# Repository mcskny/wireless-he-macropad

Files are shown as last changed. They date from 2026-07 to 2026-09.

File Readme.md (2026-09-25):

# Custom Wireless Hall Effect (HE) & Digital Macropad




A high-performance, open-source **wireless mechanical macropad** that solves the battery drain issue of wireless Hall Effect keyboards. Featuring a **Hybrid Dual-Sensor Architecture (Analog HE + Digital Switches)**, MOSFET power gating, esports-grade algorithms (Rapid Trigger, SnapTap/SOCD), 4 hardware layers, and a high-efficiency **TPS6300x Buck-Boost power system**.

---

## Gallery & Preview

<!-- Project photos and renders -->
<table>
  <tr>
    <td align="center" width="50%">
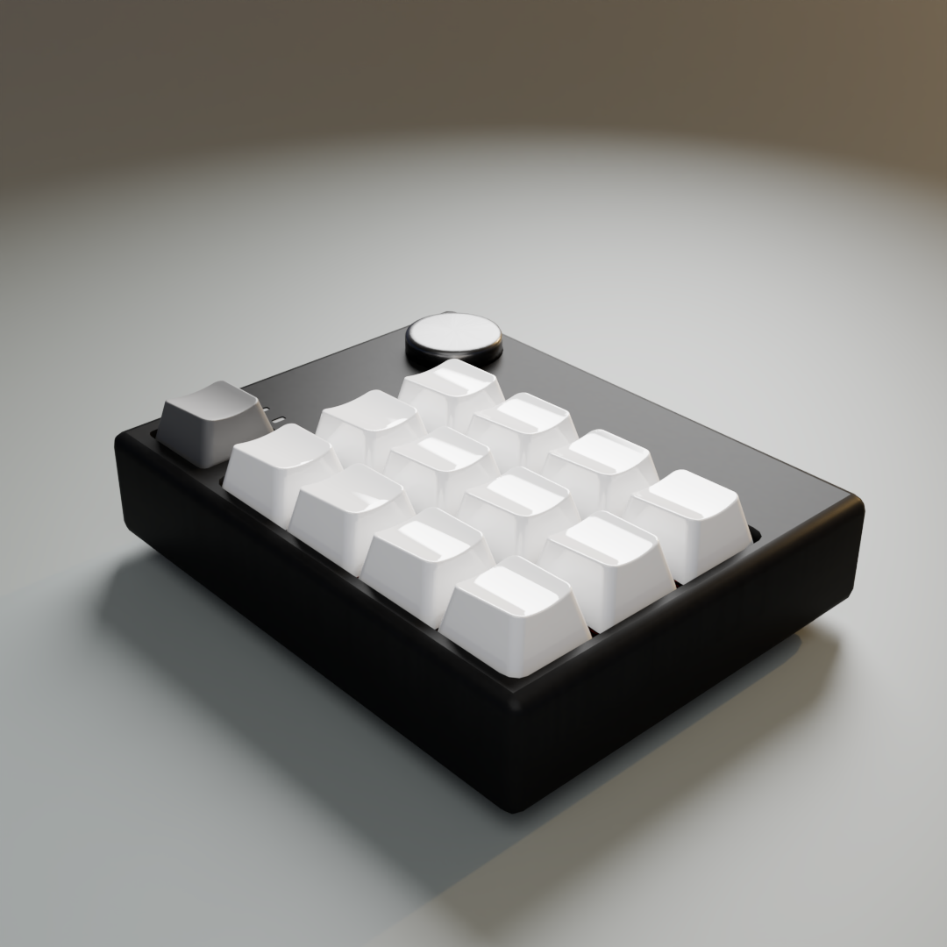
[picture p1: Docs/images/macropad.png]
3D Render
      
      <br>
      <b>3D Enclosure Render</b>
    </td>
    <td align="center" width="50%">
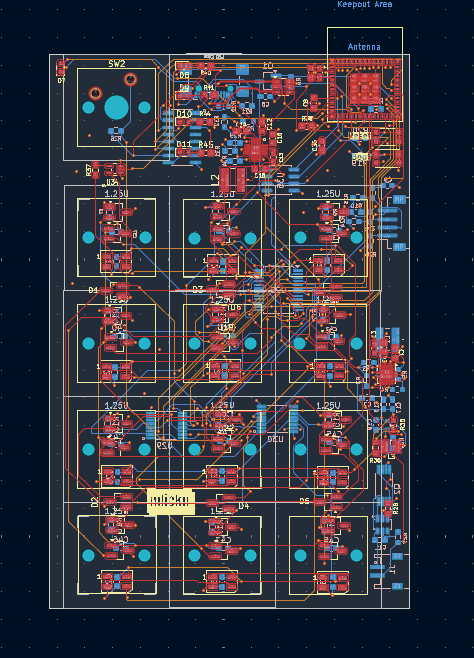
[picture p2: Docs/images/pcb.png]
PCB Design
      
      <br>
      <b>4-Layer PCB Design</b>
    </td>
  </tr>
</table>

---

## The Core Innovation

Wireless Hall Effect (HE) keyboards traditionally suffer from severe battery drain due to the constant current consumption of linear magnetic Hall ICs (~3-5mA per key). 

This project solves the battery crisis by implementing a **MOSFET-gated Hybrid Power System**:
- When idle, power to energy-hungry analog Hall sensors is completely cut via MOSFET switches.
- Keypresses are detected instantly via ultra-low-power digital switches, which trigger the MOSFET to power up the analog sensors on demand.

---

## Key Features

###  Smart Power System & Operation Modes
- **MOSFET Power Gating:** Hardware-level power cutoff for analog Hall Effect ICs.
- **3 Dynamic Power Modes:**
  -  **Digital Mode:** Operates exclusively on digital switches for ultra-low power consumption and maximum battery longevity.
  -  **Hybrid Mode (Smart Wake):** Digital switches remain active; pressing any key instantly powers on the Analog HE sensors via MOSFETs for a configurable duration.
  -  **Aggressive Mode:** Analog HE sensors remain continuously powered for zero-latency competitive esports performance.

---

## Repository & Component Architecture

This repository uses a **modular C architecture** built on top of the ESP-IDF framework:

```text
wireless-he-macropad/
├── Docs/                           # Documentation & Images
│   └── images/                     # Photos, PCB diagrams, 3D renders
├── Firmware/                       # ESP-IDF Firmware Codebase
│   ├── common/                     # Shared protocol definitions (keyboard_protocol.h)
│   ├── macropad-sender/            # Keyboard (Transmitter) Firmware
│   └── dongle-receiver/            # USB Dongle (Receiver) Firmware
|
├── Hardware/                       # KiCad PCB Files & Gerber Exports
│   ├── macropad.kicad_pro
│   ├── macropad.kicad_sch
│   ├── macropad.kicad_pcb
│   └── gerbers/                    # Production Gerber zip files
├── build_docker.bat                # Windows Docker build script
└── build_docker.sh                 # Linux/macOS Docker build script
```

---

## How to Build Firmware (Using Docker)

No local ESP-IDF toolchain installation is required. Firmware for both the **Transmitter** and **Receiver** can be built inside a clean, containerized Docker environment.

### Prerequisites
- [Docker Desktop](https://www.docker.com/products/docker-desktop/) installed and running.

### 1. Build Both Firmwares
Run the automated build script for your operating system:

**Windows (CMD / PowerShell):**
```cmd
build_docker.bat
```

**Linux / macOS:**
```bash
chmod +x build_docker.sh
./build_docker.sh
```

### 2. Clean Build Artifacts
To clear temporary CMake build caches:
```cmd
build_docker.bat clean
```

The compiled binary files (`.bin`) will be generated inside:
- **Transmitter:** `firmware/macropad-sender/build/`
- **Receiver:** `firmware/dongle-receiver/build/`

---

## How to Flash Firmware to Hardware

You can flash the generated binary files (`.bin`) to your ESP32 boards using either of the following methods:

### Method 1: Web-Based Flasher (Recommended - No Install Needed)
1. Open **[Espressif Web Serial Flasher](https://espressif.github.io/esptool-js/)** in Google Chrome or Microsoft Edge.
2. Connect your ESP32 board via USB and click **Connect**.
3. Select the generated binary files from your `build/` folder:
   - `0x1000` -> `bootloader.bin`
   - `0x8000` -> `partition-table.bin`
   - `0x10000` -> `macropad-sender.bin` (or `dongle-receiver.bin`)
4. Click **Program**.

### Method 2: Command Line (`esptool.py`)
If you have Python and `esptool` installed:
```bash
pip install esptool

# Flash Transmitter (Replace COM3 with your port)
esptool.py -p COM3 -b 921600 write_flash 0x10000 firmware/macropad-sender/build/macropad-sender.bin

# Flash Receiver
esptool.py -p COM4 -b 921600 write_flash 0x10000 firmware/dongle-receiver/build/dongle-receiver.bin
```

---

Distributed under the **MIT License**. See `LICENSE` for more information.

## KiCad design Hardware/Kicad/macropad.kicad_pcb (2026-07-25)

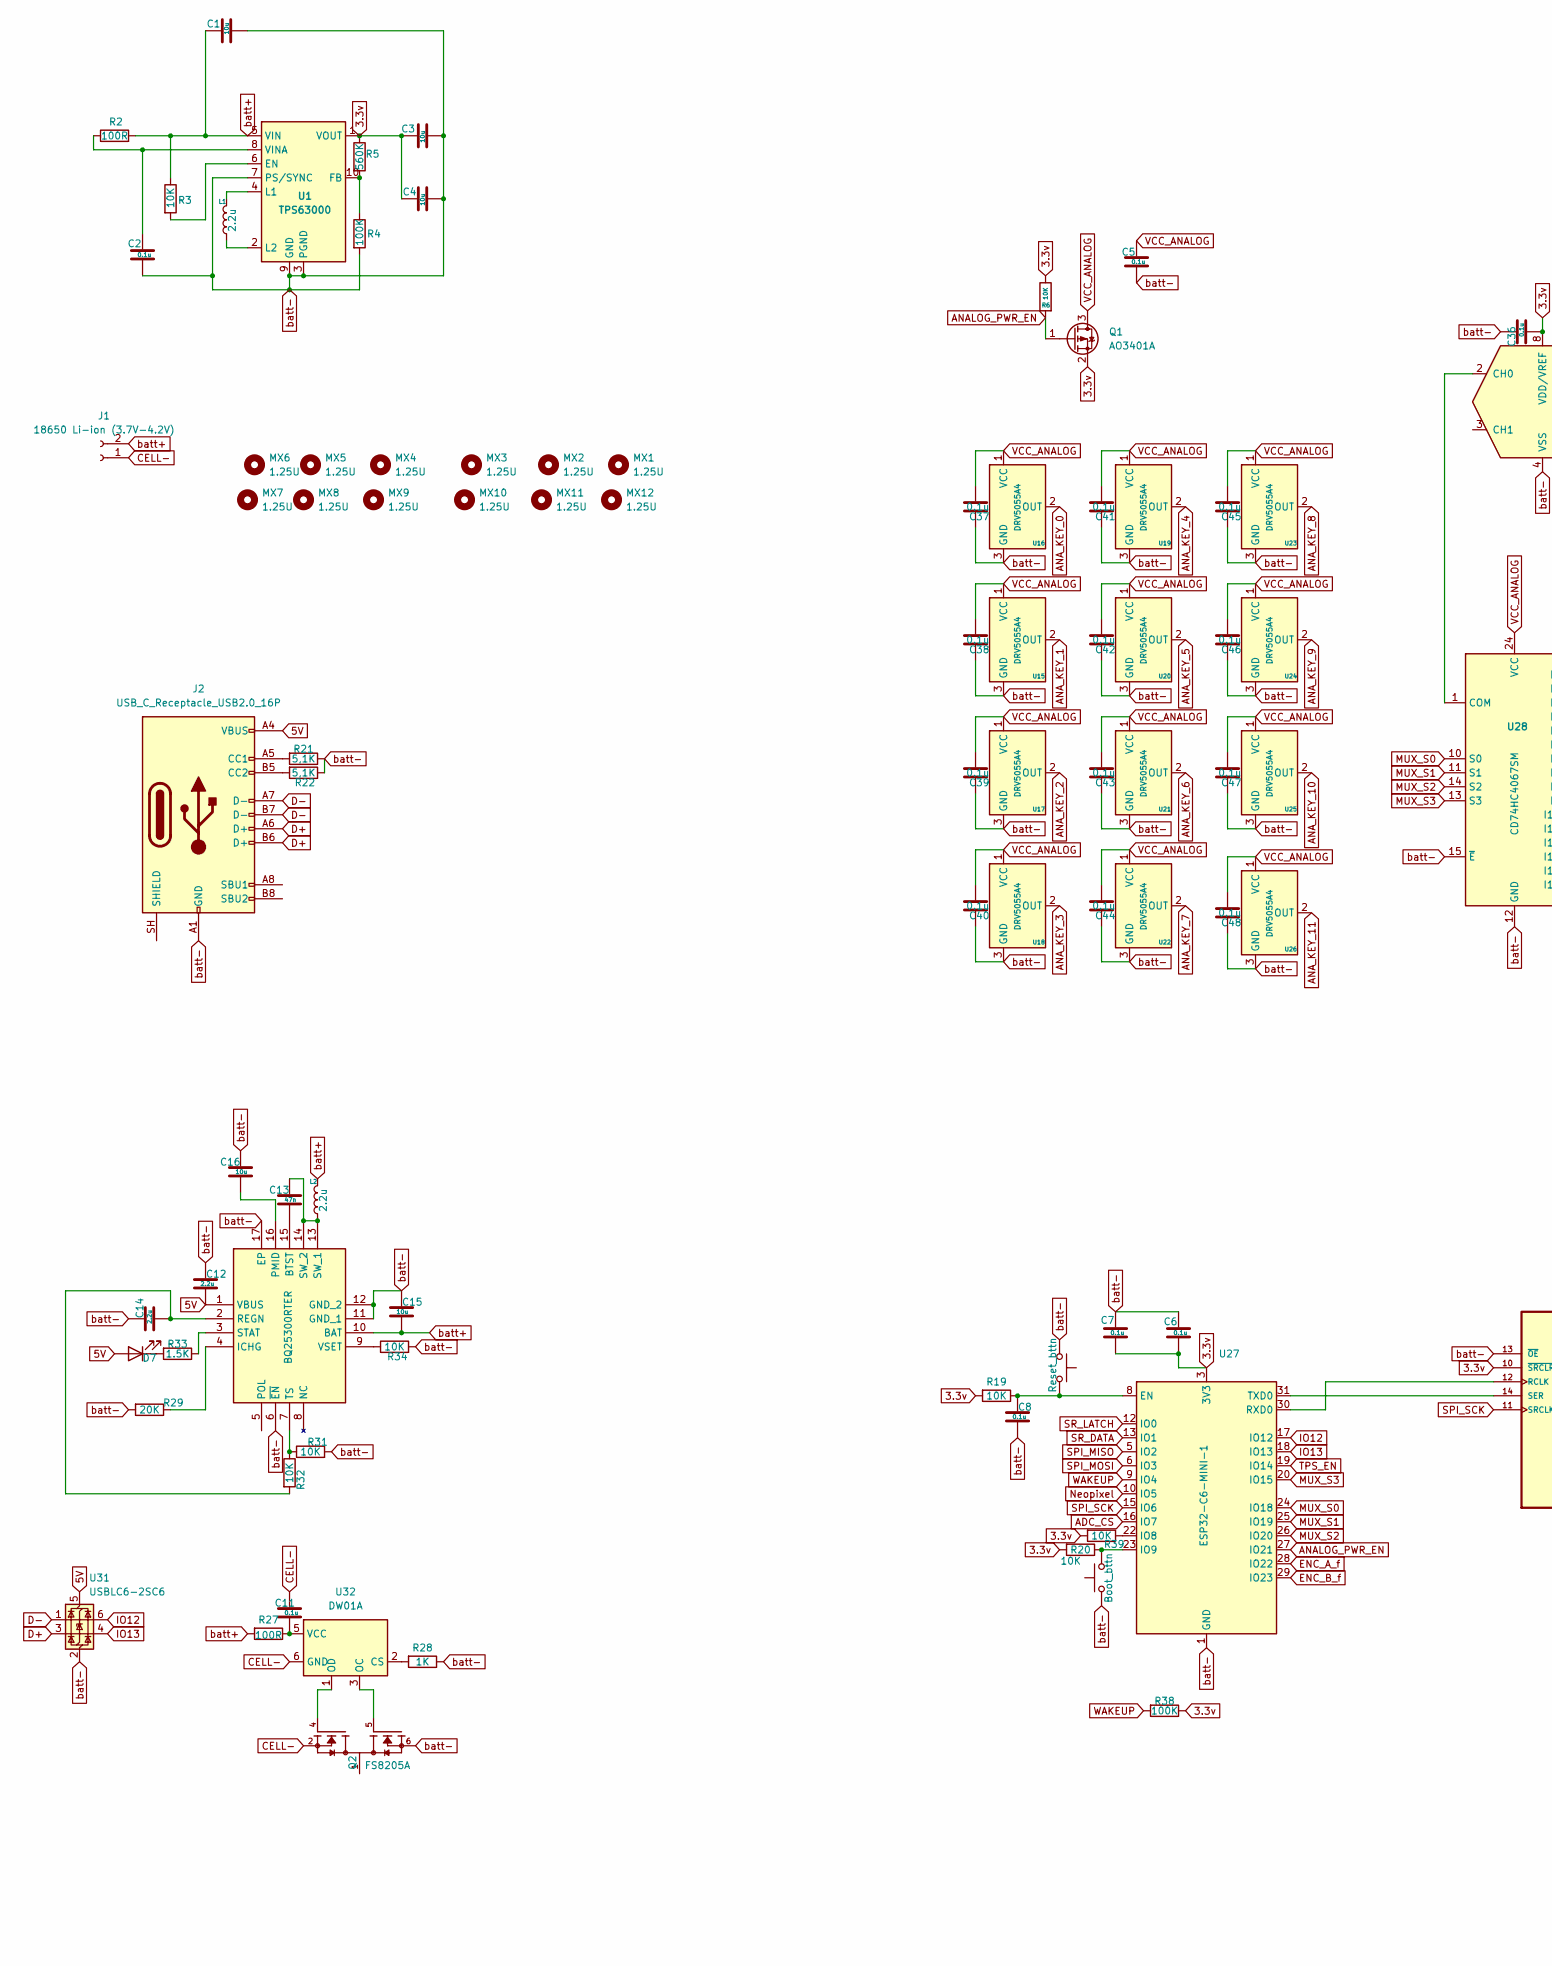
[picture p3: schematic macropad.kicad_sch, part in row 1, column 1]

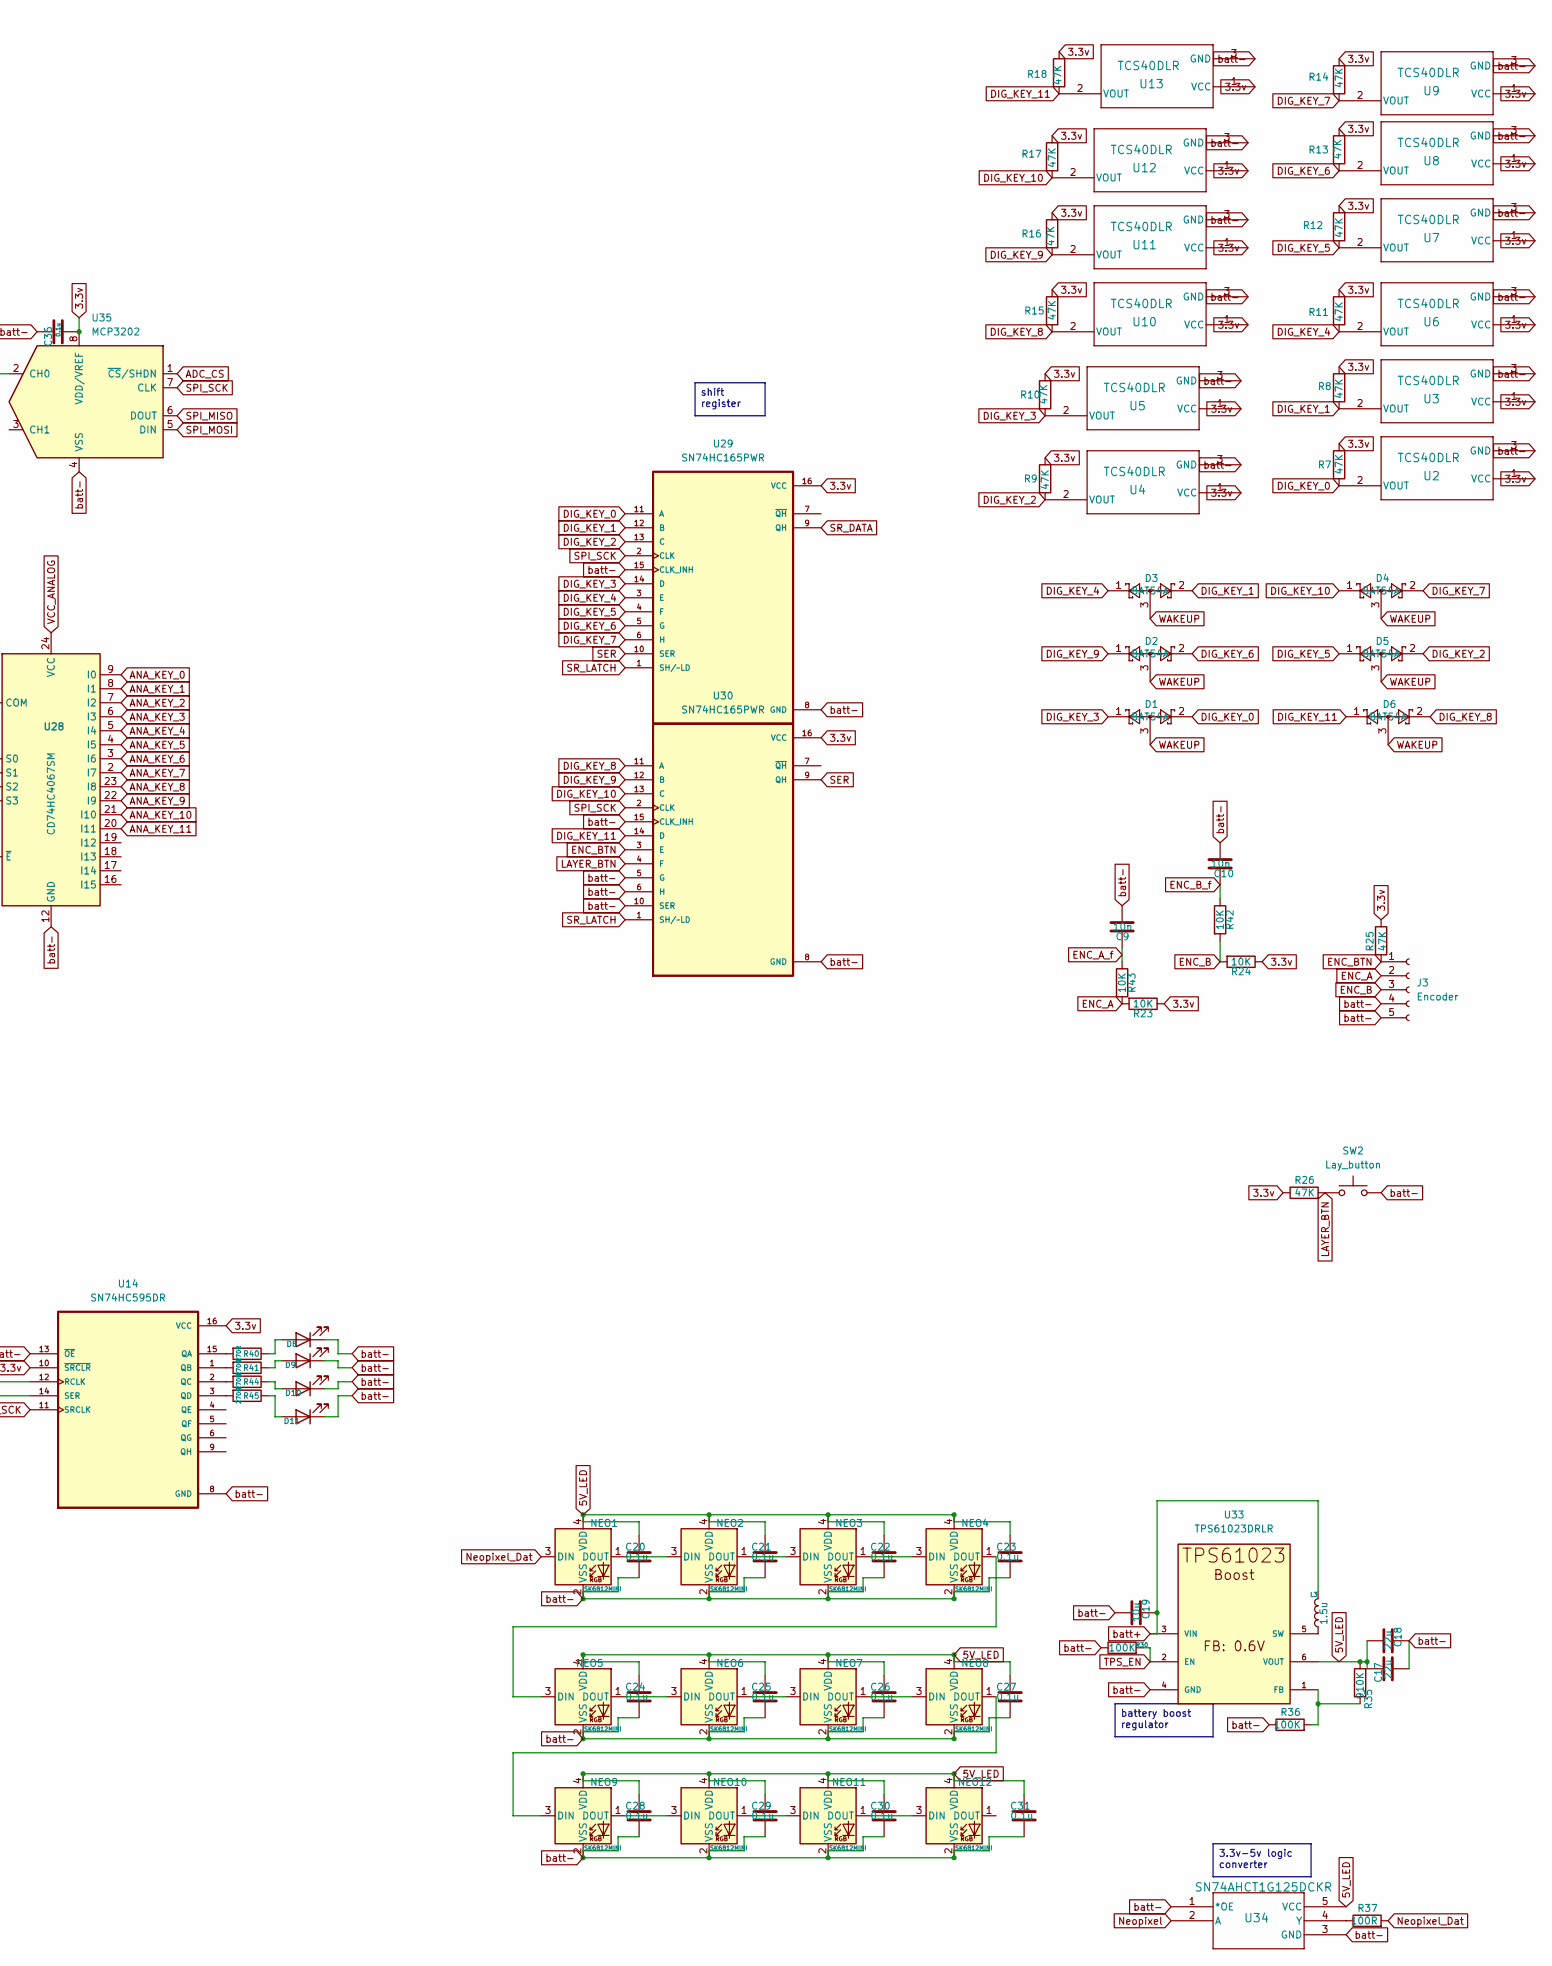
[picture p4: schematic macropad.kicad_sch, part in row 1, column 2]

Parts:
C1, C3, C4, C15, C16, C19: 10u; C_0603_1608Metric_Pad1.08x0.95mm_HandSolder
C2, C5, C6, C7, C8, C11, C20, C21, C22, C23, C24, C25, C26, C27, C28, C29, C30, C31, C36, C37, C38, C39, C40, C41, C42, C43, C44, C45, C46, C47, C48: 0.1u; C_0603_1608Metric_Pad1.08x0.95mm_HandSolder
C9, C10: 10n; C_0603_1608Metric_Pad1.08x0.95mm_HandSolder
C12, C14: 2.2u; C_0603_1608Metric_Pad1.08x0.95mm_HandSolder
C13: 47n; C_0603_1608Metric_Pad1.08x0.95mm_HandSolder
C17, C18: 22u; C_0603_1608Metric_Pad1.08x0.95mm_HandSolder
D1, D2, D3, D4, D5, D6: BAT54A; SOT-23_Handsoldering
D7, D8, D9, D10, D11: LED; LED_0603_1608Metric
J1: 18650 Li-ion (3.7V-4.2V); 648102131822
J2: USB_C_Receptacle_USB2.0_16P; USB_C_Receptacle_GCT_USB4110
J3: Encoder; SM04BPASS1TBTLFSN
L1, L2: 2.2u; SRN4030HA2R2Y
L3: 1.5u; INDC2520X100N
MX1, MX2, MX3, MX4, MX5, MX6, MX7, MX8, MX9, MX10, MX11, MX12: 1.25U; switchsocket
NEO1, NEO2, NEO3, NEO4, NEO5, NEO6, NEO7, NEO8, NEO9, NEO10, NEO11, NEO12: SK6812MINI; LED_SK6812MINI_PLCC4_3.5x3.5mm_P1.75mm
Q1: AO3401A; SOT-23_Handsoldering
Q2: FS8205A; SOP65P640X120-8N; PARTREV 1.7
R2, R27, R37: 100R; R_0603_1608Metric_Pad0.98x0.95mm_HandSolder
R3, R6, R19, R20, R23, R24, R31, R32, R34, R39, R42, R43: 10K; R_0603_1608Metric_Pad0.98x0.95mm_HandSolder
R4, R30, R36, R38: 100K; R_0603_1608Metric_Pad0.98x0.95mm_HandSolder
R5: 560K; R_0603_1608Metric_Pad0.98x0.95mm_HandSolder
R7, R8, R9, R10, R11, R12, R13, R14, R15, R16, R17, R18, R25, R26: 47K; R_0603_1608Metric_Pad0.98x0.95mm_HandSolder
R21, R22: 5,1K; R_0603_1608Metric_Pad0.98x0.95mm_HandSolder
R28: 1K; R_0603_1608Metric_Pad0.98x0.95mm_HandSolder
R29: 20K; R_0603_1608Metric_Pad0.98x0.95mm_HandSolder
R33: 1.5K; R_0603_1608Metric_Pad0.98x0.95mm_HandSolder
R35: 910K; R_0603_1608Metric_Pad0.98x0.95mm_HandSolder
R40, R41, R44, R45: 270R; R_0603_1608Metric_Pad0.98x0.95mm_HandSolder
SW1: Boot_bttn; SW_Push_1P1T_NO_CK_KMR2
SW2: Lay_button; SW_Cherry_MX_1.00u_PCB
SW3: Reset_bttn; SW_Push_1P1T_NO_CK_KMR2
U1: TPS63000; Texas_DRC0010J_ThermalVias
U2, U3, U4, U5, U6, U7, U8, U9, U10, U11, U12, U13: TCS40DLR; SOT-23_Handsoldering
U14: SN74HC595DR; SOIC127P600X175-16N
U15, U16, U17, U18, U19, U20, U21, U22, U23, U24, U25, U26: DRV5055A4; SOT-23_Handsoldering
U27: ESP32-C6-MINI-1
U28: CD74HC4067SM; SSOP-24_5.3x8.2mm_P0.65mm
U29, U30: SN74HC165PWR; SOP65P640X120-16N
U31: USBLC6-2SC6; SOT-23-6
U32: DW01A; SOT-23-6
U33: TPS61023DRLR; SOT563-ORI
U34: SN74AHCT1G125DCKR; DCK5
U35: MCP3202; SOIC-8_3.9x4.9mm_P1.27mm
Z1: BQ25300RTER; QFN50P300X300X80-17N-D; Mouser Part Number 595-BQ25300RTER

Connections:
3.3v: C3.1, C4.1, C6.2, C7.2, C36.2, Q1.2 (S), R5.1, R6.1, R7.2, R8.2, R9.2, R10.2, R11.2, R12.2, R13.2, R14.2, R15.2, R16.2, R17.2, R18.2, R19.2, R20.2, R23.1, R24.1, R25.1, R26.1, R38.1, R39.2, U1.1 (VOUT), U2.1 (VCC), U3.1 (VCC), U4.1 (VCC), U5.1 (VCC), U6.1 (VCC), U7.1 (VCC), U8.1 (VCC), U9.1 (VCC), U10.1 (VCC), U11.1 (VCC), U12.1 (VCC), U13.1 (VCC), U14.10 (~SRCLR), U14.16 (VCC), U27.3 (3V3), U29.16 (VCC), U30.16 (VCC), U35.8 (VDD/VREF)
5V: C12.1, D7.2 (A), J2.A4 (VBUS), J2.A9 (VBUS), J2.B4 (VBUS), J2.B9 (VBUS), U31.5 (VBUS), Z1.1 (VBUS)
5V_LED: C17.1, C18.2, C20.1, C21.1, C22.1, C23.1, C24.1, C25.1, C26.1, C27.1, C28.1, C29.1, C30.1, C31.1, NEO1.4 (VDD), NEO2.4 (VDD), NEO3.4 (VDD), NEO4.4 (VDD), NEO5.4 (VDD), NEO6.4 (VDD), NEO7.4 (VDD), NEO8.4 (VDD), NEO9.4 (VDD), NEO10.4 (VDD), NEO11.4 (VDD), NEO12.4 (VDD), R35.2, U33.6 (VOUT), U34.5 (VCC)
ADC_CS: U27.16 (IO7), U35.1 (~CS/SHDN)
ANALOG_PWR_EN: Q1.1 (G), R6.2, U27.27 (IO21)
ANA_KEY_0: U16.2 (OUT), U28.9 (I0)
ANA_KEY_1: U15.2 (OUT), U28.8 (I1)
ANA_KEY_2: U17.2 (OUT), U28.7 (I2)
ANA_KEY_3: U18.2 (OUT), U28.6 (I3)
ANA_KEY_4: U19.2 (OUT), U28.5 (I4)
ANA_KEY_5: U20.2 (OUT), U28.4 (I5)
ANA_KEY_6: U21.2 (OUT), U28.3 (I6)
ANA_KEY_7: U22.2 (OUT), U28.2 (I7)
ANA_KEY_8: U23.2 (OUT), U28.23 (I8)
ANA_KEY_9: U24.2 (OUT), U28.22 (I9)
ANA_KEY_10: U25.2 (OUT), U28.21 (I10)
ANA_KEY_11: U26.2 (OUT), U28.20 (I11)
CELL-: C11.1, J1.1, Q2.2, Q2.3, U32.6 (GND)
D+: J2.A6 (D+), J2.B6 (D+), U31.3 (I/O2)
D-: J2.A7 (D-), J2.B7 (D-), U31.1 (I/O1)
DIG_KEY_0: D1.2, R7.1, U2.2 (VOUT), U29.11 (A)
DIG_KEY_1: D3.2, R8.1, U3.2 (VOUT), U29.12 (B)
DIG_KEY_2: D5.2, R9.1, U4.2 (VOUT), U29.13 (C)
DIG_KEY_3: D1.1, R10.1, U5.2 (VOUT), U29.14 (D)
DIG_KEY_4: D3.1, R11.1, U6.2 (VOUT), U29.3 (E)
DIG_KEY_5: D5.1, R12.1, U7.2 (VOUT), U29.4 (F)
DIG_KEY_6: D2.2, R13.1, U8.2 (VOUT), U29.5 (G)
DIG_KEY_7: D4.2, R14.1, U9.2 (VOUT), U29.6 (H)
DIG_KEY_8: D6.2, R15.1, U10.2 (VOUT), U30.11 (A)
DIG_KEY_9: D2.1, R16.1, U11.2 (VOUT), U30.12 (B)
DIG_KEY_10: D4.1, R17.1, U12.2 (VOUT), U30.13 (C)
DIG_KEY_11: D6.1, R18.1, U13.2 (VOUT), U30.14 (D)
ENC_A: J3.2, R23.2, R43.2
ENC_A_f: C9.1, R43.1, U27.28 (IO22)
ENC_B: J3.3, R24.2, R42.2
ENC_BTN: J3.1, R25.2, U30.3 (E)
ENC_B_f: C10.1, R42.1, U27.29 (IO23)
IO12: U27.17 (IO12), U31.6 (I/O1)
IO13: U27.18 (IO13), U31.4 (I/O2)
LAYER_BTN: R26.2, SW2.1, U30.4 (F)
MUX_S0: U27.24 (IO18), U28.10 (S0)
MUX_S1: U27.25 (IO19), U28.11 (S1)
MUX_S2: U27.26 (IO20), U28.14 (S2)
MUX_S3: U27.20 (IO15), U28.13 (S3)
Neopixel: U27.10 (IO5), U34.2 (A)
Neopixel_Dat: NEO1.3 (DIN), R37.2
unnamed: D7.1 (K), R33.2
unnamed: D8.2 (A), R40.1
unnamed: D9.2 (A), R41.1
unnamed: D10.2 (A), R44.1
unnamed: D11.2 (A), R45.1
unnamed: J2.A5 (CC1), R21.2
unnamed: J2.B5 (CC2), R22.2
unnamed: NEO1.1 (DOUT), NEO2.3 (DIN)
unnamed: NEO2.1 (DOUT), NEO3.3 (DIN)
unnamed: NEO3.1 (DOUT), NEO4.3 (DIN)
unnamed: NEO4.1 (DOUT), NEO5.3 (DIN)
unnamed: NEO5.1 (DOUT), NEO6.3 (DIN)
unnamed: NEO6.1 (DOUT), NEO7.3 (DIN)
unnamed: NEO7.1 (DOUT), NEO8.3 (DIN)
unnamed: NEO8.1 (DOUT), NEO9.3 (DIN)
unnamed: NEO9.1 (DOUT), NEO10.3 (DIN)
unnamed: NEO10.1 (DOUT), NEO11.3 (DIN)
unnamed: NEO11.1 (DOUT), NEO12.3 (DIN)
unnamed: Q2.1, Q2.8
unnamed: R3.2, U1.6 (EN)
unnamed: R4.1, R5.2, U1.10 (FB)
unnamed: L1.2, U1.4 (L1)
unnamed: L1.1, U1.2 (L2)
unnamed: C2.1, R2.1, U1.8 (VINA)
unnamed: R40.2, U14.15 (QA)
unnamed: R41.2, U14.1 (QB)
unnamed: R44.2, U14.2 (QC)
unnamed: R45.2, U14.3 (QD)
unnamed: U14.7 (QH), U14.9 (QH)
unnamed: U14.12 (RCLK), U27.30 (RXD0)
unnamed: U14.14 (SER), U27.31 (TXD0)
unnamed: C8.2, R19.1, SW3.2, U27.8 (EN)
unnamed: R39.1, U27.22 (IO8)
unnamed: R20.1, SW1.2, U27.23 (IO9)
unnamed: U28.1 (COM), U35.2 (CH0)
unnamed: R28.2, U32.2 (CS)
unnamed: Q2.5, U32.3 (OC)
unnamed: Q2.4, U32.1 (OD)
unnamed: C11.2, R27.1, U32.5 (VCC)
unnamed: R35.1, R36.2, U33.1 (FB)
unnamed: L3.1, U33.5 (SW)
unnamed: R37.1, U34.4 (Y)
unnamed: C13.1, Z1.15 (BTST)
unnamed: R29.1, Z1.4 (ICHG)
unnamed: C16.1, Z1.16 (PMID)
unnamed: C14.1, R32.2, Z1.2 (REGN)
unnamed: R33.1, Z1.3 (STAT)
unnamed: C13.2, L2.1, Z1.13 (SW_1), Z1.14 (SW_2)
unnamed: R31.1, R32.1, Z1.7 (TS)
unnamed: R34.1, Z1.9 (VSET)
SER: U29.10 (SER), U30.9 (QH)
SPI_MISO: U27.5 (IO2), U35.6 (DOUT)
SPI_MOSI: U27.6 (IO3), U35.5 (DIN)
SPI_SCK: U14.11 (SRCLK), U27.15 (IO6), U29.2 (CLK), U30.2 (CLK), U35.7 (CLK)
SR_DATA: U27.13 (IO1), U29.9 (QH)
SR_LATCH: U27.12 (IO0), U29.1 (SH/~LD), U30.1 (SH/~LD)
TPS_EN: R30.2, U27.19 (IO14), U33.2 (EN)
VCC_ANALOG: C5.1, C37.2, C38.2, C39.2, C40.2, C41.2, C42.2, C43.2, C44.2, C45.2, C46.2, C47.2, C48.2, Q1.3 (D), U15.1 (VCC), U16.1 (VCC), U17.1 (VCC), U18.1 (VCC), U19.1 (VCC), U20.1 (VCC), U21.1 (VCC), U22.1 (VCC), U23.1 (VCC), U24.1 (VCC), U25.1 (VCC), U26.1 (VCC), U28.24 (VCC)
WAKEUP: D1.3, D2.3, D3.3, D4.3, D5.3, D6.3, R38.2, U27.9 (IO4)
batt+: C1.1, C15.1, C19.1, J1.2, L2.2, L3.2, R2.2, R3.1, R27.2, U1.5 (VIN), U33.3 (VIN), Z1.10 (BAT)
batt-: C1.2, C2.2, C3.2, C4.2, C5.2, C6.1, C7.1, C8.1, C9.2, C10.2, C12.2, C14.2, C15.2, C16.2, C17.2, C18.1, C19.2, C20.2, C21.2, C22.2, C23.2, C24.2, C25.2, C26.2, C27.2, C28.2, C29.2, C30.2, C31.2, C36.1, C37.1, C38.1, C39.1, C40.1, C41.1, C42.1, C43.1, C44.1, C45.1, C46.1, C47.1, C48.1, D8.1 (K), D9.1 (K), D10.1 (K), D11.1 (K), J2.A1 (GND), J2.A12 (GND), J2.B1 (GND), J2.B12 (GND), J3.4, J3.5, NEO1.2 (VSS), NEO2.2 (VSS), NEO3.2 (VSS), NEO4.2 (VSS), NEO5.2 (VSS), NEO6.2 (VSS), NEO7.2 (VSS), NEO8.2 (VSS), NEO9.2 (VSS), NEO10.2 (VSS), NEO11.2 (VSS), NEO12.2 (VSS), Q2.6, Q2.7, R4.2, R21.1, R22.1, R28.1, R29.2, R30.1, R31.2, R34.2, R36.1, SW1.1, SW2.2, SW3.1, U1.3 (PGND), U1.7 (PS/SYNC), U1.9 (GND), U1.11 (PGND), U2.3 (GND), U3.3 (GND), U4.3 (GND), U5.3 (GND), U6.3 (GND), U7.3 (GND), U8.3 (GND), U9.3 (GND), U10.3 (GND), U11.3 (GND), U12.3 (GND), U13.3 (GND), U14.8 (GND), U14.13 (~OE), U15.3 (GND), U16.3 (GND), U17.3 (GND), U18.3 (GND), U19.3 (GND), U20.3 (GND), U21.3 (GND), U22.3 (GND), U23.3 (GND), U24.3 (GND), U25.3 (GND), U26.3 (GND), U27.1 (GND), U27.2 (GND), U27.11 (GND), U27.14 (GND), U27.36 (GND), U27.37 (GND), U27.38 (GND), U27.39 (GND), U27.40 (GND), U27.41 (GND), U27.42 (GND), U27.43 (GND), U27.44 (GND), U27.45 (GND), U27.46 (GND), U27.47 (GND), U27.48 (GND), U27.49 (GND), U27.50 (GND), U27.51 (GND), U27.52 (GND), U27.53 (GND), U28.12 (GND), U28.15 (~E), U29.8 (GND), U29.15 (CLK_INH), U30.5 (G), U30.6 (H), U30.8 (GND), U30.10 (SER), U30.15 (CLK_INH), U31.2 (GND), U33.4 (GND), U34.1 (*OE), U34.3 (GND), U35.4 (VSS), Z1.6 (~EN), Z1.11 (GND_1), Z1.12 (GND_2), Z1.17 (EP)

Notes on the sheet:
3.3v-5v logic converter
battery boost regulator
shift register

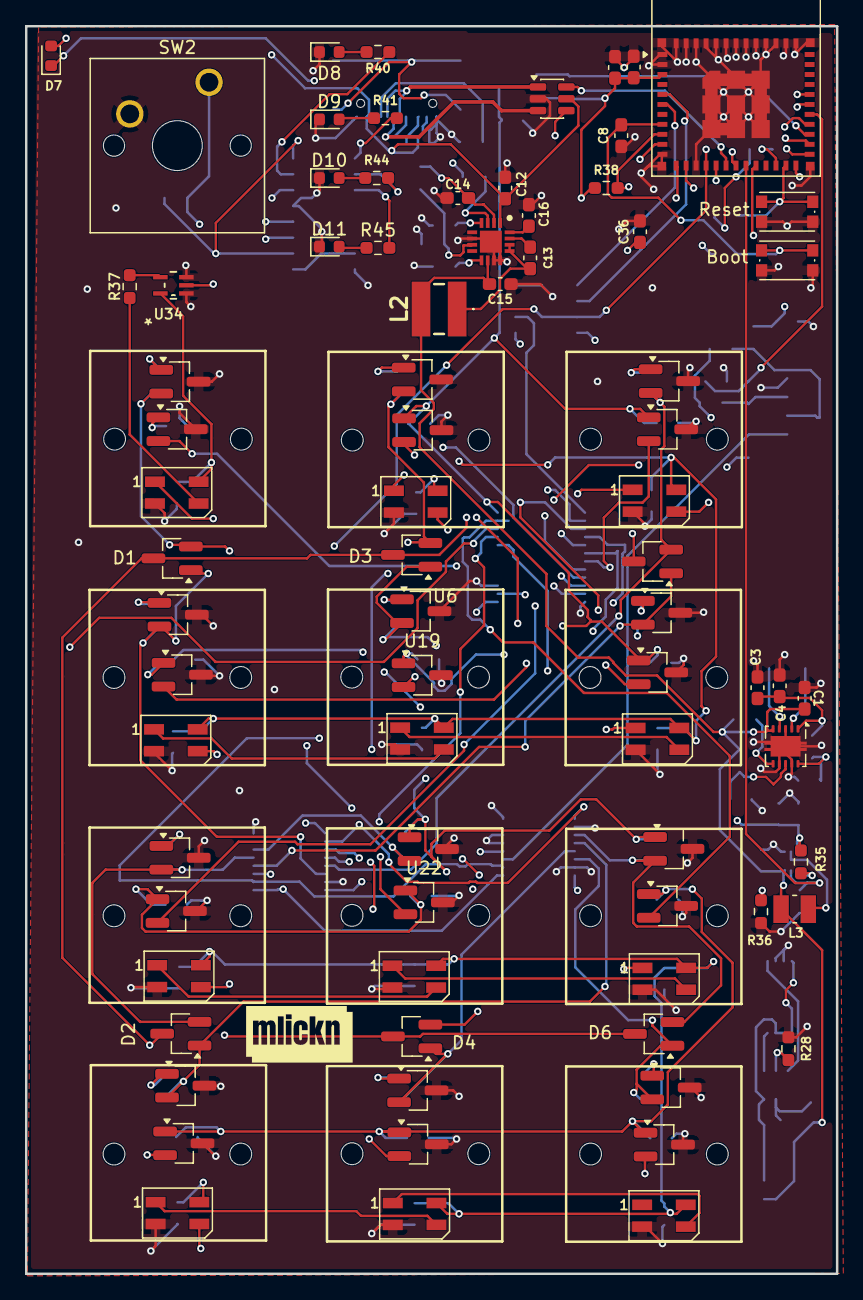
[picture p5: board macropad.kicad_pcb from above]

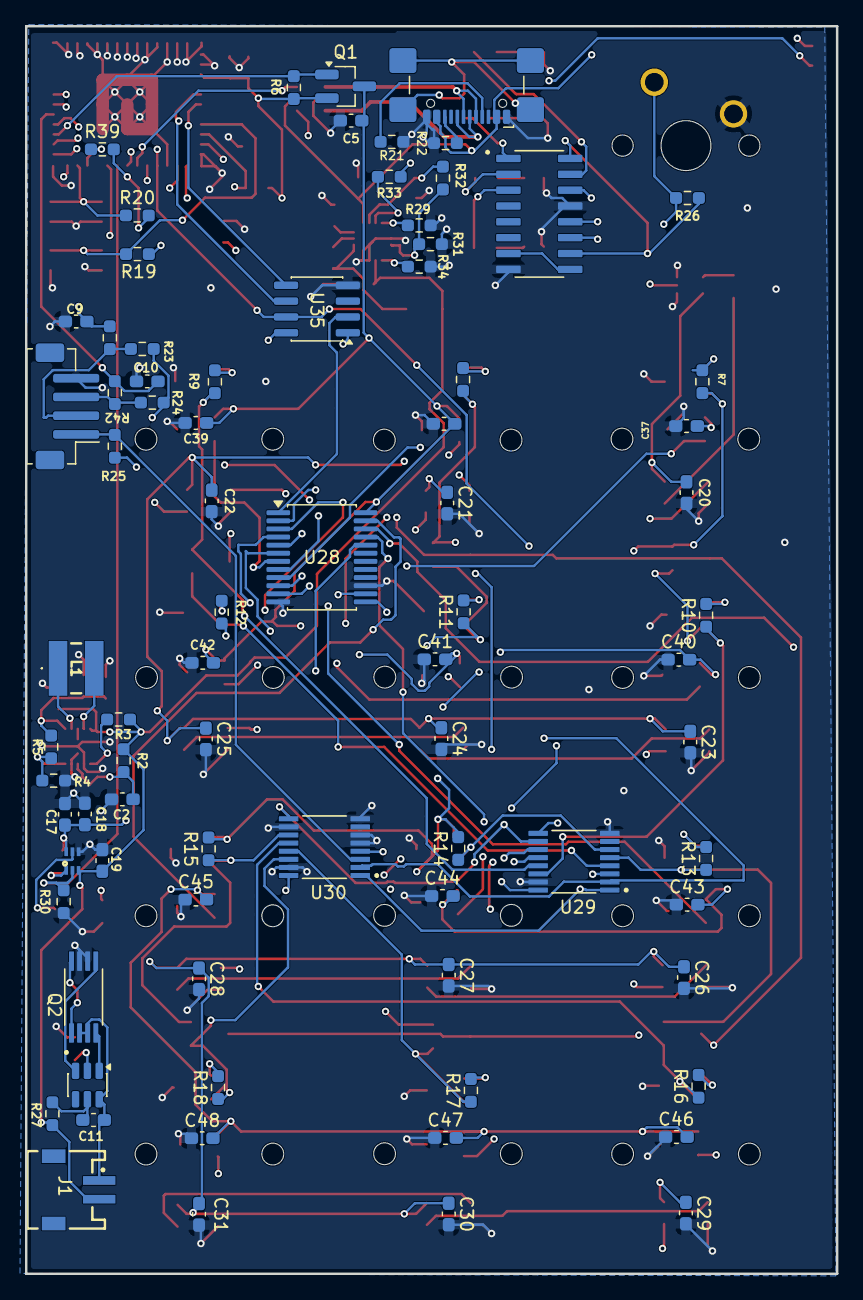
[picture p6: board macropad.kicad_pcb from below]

Board: 4 copper layers, 65.0 x 100.0 mm, 170 parts (80 on the bottom side), 107 nets.

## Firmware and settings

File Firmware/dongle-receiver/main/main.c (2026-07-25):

// SPDX-License-Identifier: MIT-only
// Copyright (c) 2026 ESP32-S3 Dongle. All rights reserved.

/**
 * @file main.c
 * @brief ESP32-S3 Dongle ana giris noktasi. Bölüm 2 state machine.
 *
 * Iki mod:
 *   - NORMAL_MODE: ESP-NOW RX + Hall motoru + USB HID 1000Hz
 *   - CONFIG_AP_MODE: Wi-Fi AP + WebSocket kalibrasyon
 *
 * Config_Mode_Request (C6 status bit veya web exit) ile geçiş.
 */

#include <stdio.h>
#include <string.h>
#include "freertos/FreeRTOS.h"
#include "freertos/task.h"
#include "esp_log.h"
#include "esp_system.h"
#include "esp_check.h"
#include "esp_timer.h"
#include "driver/gpio.h"

#include "pinout.h"
#include "system_state.h"

#include "nvs_store.h"
#include "espnow_rx.h"
#include "packet_decoder.h"
#include "watchdog.h"
#include "hall_effect_engine.h"
#include "layer_manager.h"
#include "macro_engine.h"
#include "usb_hid.h"
#include "usb_power.h"
#include "config_ap.h"

static const char *TAG = "s3dongle";

/* --- Paket zamanlama istatistikleri (1 saniyede bir rapor) --- */
static uint32_t s_last_packet_us = 0;
static uint32_t s_interval_min_us = UINT32_MAX;
static uint32_t s_interval_max_us = 0;
static uint64_t s_interval_sum_us = 0;
static uint32_t s_interval_count = 0;
static uint32_t s_last_report_ms = 0;
static uint32_t s_last_report_packets_lost = 0;
static uint32_t s_packets_reordered = 0;
static uint32_t s_last_report_packets_reordered = 0;

/** Sira karisikligi icin makul ust sinir: bunun ustundeki farklar
 *  gercek kayip yerine "reorder/duplicate" sayilir (yanlis pozitifi onler). */
#define MAX_PLAUSIBLE_LOSS 50

/** C6 MAC string parse. */
static void parse_mac(const char *str, uint8_t mac[6])
{
    if (sscanf(str, "%2hhx:%2hhx:%2hhx:%2hhx:%2hhx:%2hhx",
               &mac[0], &mac[1], &mac[2], &mac[3], &mac[4], &mac[5]) != 6) {
        ESP_LOGW(TAG, "MAC parse hatasi, default FF");
        memset(mac, 0xFF, 6);
    }
}

/**
 * @brief Tum bilesenleri baslatir (Bölüm 1).
 */
static esp_err_t init_subsystems(s3_system_state_t *state)
{
    memset(state, 0, sizeof(*state));
    state->mode = S3_MODE_NORMAL;

    /* 1. NVS + kalibrasyon (Bölüm 1.1) */
    ESP_RETURN_ON_ERROR(nvs_store_init(), TAG, "nvs_store_init");
    ESP_RETURN_ON_ERROR(nvs_store_load_calibration(&state->calibration), TAG, "load_calib");

    /* 2. ESP-NOW RX (Bölüm 1.2 + 3) */
    uint8_t c6_mac[6] = {0};
    parse_mac(CONFIG_C6_PEER_MAC, c6_mac);
    ESP_RETURN_ON_ERROR(espnow_rx_init(c6_mac, CONFIG_ESPNOW_CHANNEL), TAG, "espnow_rx");

    /* 3. Watchdog (Bölüm 3) */
    ESP_RETURN_ON_ERROR(watchdog_init(CONFIG_C6_WATCHDOG_TIMEOUT_MS), TAG, "watchdog");

    /* 4. Hall engine + layer + macro (Bölüm 4 + 5) */
    ESP_RETURN_ON_ERROR(hall_engine_init(), TAG, "hall_engine");
    layer_manager_init();
    macro_engine_init();

    /* 5. USB HID + power (Bölüm 6) */
    ESP_RETURN_ON_ERROR(usb_hid_init(), TAG, "usb_hid");
    ESP_RETURN_ON_ERROR(usb_power_init(), TAG, "usb_power");

    /* 6. BOOT button (GPIO0) - CONFIG_AP gecisi icin */
    gpio_config_t boot_btn_cfg = {
        .pin_bit_mask = (1ULL << PIN_BOOT_BUTTON),
        .mode = GPIO_MODE_INPUT,
        .pull_up_en = GPIO_PULLUP_ENABLE,
        .pull_down_en = GPIO_PULLDOWN_DISABLE,
        .intr_type = GPIO_INTR_DISABLE,
    };
    ESP_RETURN_ON_ERROR(gpio_config(&boot_btn_cfg), TAG, "boot_button");

    ESP_LOGI(TAG, "Tum bilesenler baslatildi (NORMAL_MODE)");
    return ESP_OK;
}

/**
 * @brief BOOT button (GPIO0) kısa basış kontrolü.
 *
 * Debounce + kısa basış algılama (<1sn). Kısa basış → true (config toggle).
 *
 * @param now_ms Su anki zaman (ms).
 * @return true = kısa basış algılandı (CONFIG_AP toggle).
 */
static bool check_boot_button(uint32_t now_ms)
{
    static bool s_prev_pressed = false;  /* idle: HIGH (pull-up) */
    static uint32_t s_press_ms = 0;

    bool pressed = (gpio_get_level(PIN_BOOT_BUTTON) == 0);  /* LOW = pressed */

    if (!s_prev_pressed && pressed) {
        /* HIGH → LOW: basılma */
        s_press_ms = now_ms;
    } else if (s_prev_pressed && !pressed) {
        /* LOW → HIGH: bırakma */
        uint32_t duration = now_ms - s_press_ms;
        s_prev_pressed = pressed;
        if (duration >= 50 && duration < 1000) {
            ESP_LOGI(TAG, "BOOT button kısa basış (%lu ms) → config toggle",
                     (unsigned long)duration);
            return true;
        }
    }
    s_prev_pressed = pressed;
    return false;
}

/**
 * @brief Sira numarasi farkindan kayip/reorder ayrimi yapar.
 *
 * counter 8-bit wrap-around'lu bir sayac. Normal durumda ardisik paketler
 * arasinda counter 1 artar (diff=1, kayip=0). Paket kaybolduysa diff>1
 * olur (kayip = diff-1). Ancak yuksek hizda ESP-NOW paketleri bazen
 * siralamayi bozarak (out-of-order) dongle'a ulasabilir; bu durumda
 * counter GERIYE gidebilir (diff kucuk/negatif gorunur, wrap sonrasi
 * yanlislikla 250+ gibi devasa "kayip" hesaplanir). Bunu onlemek icin:
 *   - diff makul bir aralikta (1..MAX_PLAUSIBLE_LOSS) ise gercek kayip say.
 *   - diff bu aralik disindaysa (asiri buyuk ya da <=0) reorder/duplicate
 *     say, kayip sayacina ekleme (yanlis pozitifi onler).
 */
static void update_sequence_stats(s3_system_state_t *state, uint8_t counter,
                                  bool is_first_packet)
{
    if (is_first_packet) {
        state->last_sequence_number = counter;
        return;
    }

    int16_t diff = (int16_t)counter - (int16_t)state->last_sequence_number;
    if (diff <= 0) {
        diff += 256;  /* wrap-around */
    }

    if (diff >= 1 && diff <= MAX_PLAUSIBLE_LOSS) {
        state->packets_lost += (uint32_t)(diff - 1);
    } else {
        /* Mantiksiz buyuk fark: sira karisikligi/duplicate, kayip sayma */
        s_packets_reordered++;
    }

    state->last_sequence_number = counter;
}

/**
 * @brief NORMAL_MODE: bir döngü adimi (Bölüm 2-6).
 * @return true = CONFIG_AP_MODE'a geçiş isteği, false = devam.
 */
static bool normal_mode_step(s3_system_state_t *state)
{
    uint32_t now_ms = (uint32_t)(esp_timer_get_time() / 1000);

    /* 1. ESP-NOW RX: paket bekle (1ms = 1000Hz) */
    espnow_rx_packet_t pkt;
    esp_err_t ret = espnow_rx_get_packet(&pkt, 1);

    if (ret == ESP_OK) {
        /* 2. Watchdog feed (Bölüm 3) */
        watchdog_feed();
        state->c6_connection_watchdog = 0;

        /* Paketler-arasi sure olcumu (istatistik icin) */
        uint32_t now_us = (uint32_t)esp_timer_get_time();
        if (s_last_packet_us != 0) {
            uint32_t interval_us = now_us - s_last_packet_us;
            if (interval_us < s_interval_min_us) s_interval_min_us = interval_us;
            if (interval_us > s_interval_max_us) s_interval_max_us = interval_us;
            s_interval_sum_us += interval_us;
            s_interval_count++;
        }
        s_last_packet_us = now_us;

        /* 3. Packet decode (Bölüm 3) */
        uint8_t counter, status;
        uint16_t buttons;
        int8_t enc_delta;
        uint16_t analog[12] = {0};

        bool has_analog = (pkt.len == 23);
        if (has_analog) {
            packet_decode_full(pkt.data, &counter, &status, &buttons,
                               &enc_delta, analog);
        } else {
            packet_decode_fast(pkt.data, &counter, &status, &buttons,
                               &enc_delta);
        }

        /* Seq kayip/reorder takibi (duzeltilmis) */
        bool is_first_packet = (state->packets_received == 0);
        update_sequence_stats(state, counter, is_first_packet);
        state->packets_received++;

        /* Status parse: SW2, config mode request */
        power_mode_t c6_mode;
        bool sw2_pressed, enc_btn, flag_15, battery_dead, charging, charge_complete;
        packet_parse_status(status, &c6_mode, &sw2_pressed, &enc_btn,
                            &flag_15, &battery_dead, &charging, &charge_complete);

        /* Config mode request (Bölüm 2: Config_Mode_Request biti) */
        /* Simdilik: SW2 + ENC_BTN ayni anda basili → config mode (placeholder) */
        if (sw2_pressed && enc_btn) {
            ESP_LOGI(TAG, "Config mode request (SW2+ENC_BTN)");
            return true;  /* CONFIG_AP_MODE'a geç */
        }

        /* 4. Hall Effect motoru (Bölüm 4, sadece 23B pakette) */
        if (has_analog) {
            hall_engine_process(analog, &state->calibration, state->keys,
                                state->active_keys, &state->joystick_x,
                                &state->joystick_y);
        }

        /* 5. Layer update (Bölüm 5.1: SW2 kisa/uzun basis) */
        state->current_layer_index = layer_manager_update(sw2_pressed, now_ms);

        /* 6. USB HID report (Bölüm 6) */
        if (!macro_engine_is_running()) {
            usb_hid_send_keyboard(state->active_keys,
                                  state->calibration.key_mappings,
                                  state->current_layer_index);
        }
        usb_hid_send_gamepad(state->joystick_x, state->joystick_y);
    } else {
        /* Paket yok: watchdog check (Bölüm 3) */
        if (watchdog_is_expired(now_ms)) {
            /* C6 bağlantı koptu: tum tuşlari birak */
            hall_engine_release_all(state->keys, state->active_keys,
                                    &state->joystick_x, &state->joystick_y);
            usb_hid_release_all();
        }
    }

    /* 7. Macro tick (Bölüm 5.2) */
    macro_engine_tick(now_ms);

    /* 8. USB suspend check (Bölüm 6.3) */
    if (usb_hid_is_suspended() && !usb_power_is_suspended()) {
        usb_power_on_suspend();
    } else if (!usb_hid_is_suspended() && usb_power_is_suspended()) {
        usb_power_on_resume();
    }

    /* Saniyede bir istatistik raporu */
    if (now_ms - s_last_report_ms >= 1000) {
        uint32_t avg_us = (s_interval_count > 0)
                           ? (uint32_t)(s_interval_sum_us / s_interval_count)
                           : 0;
        float hz = (avg_us > 0) ? (1000000.0f / (float)avg_us) : 0.0f;
        uint32_t loss_window = state->packets_lost - s_last_report_packets_lost;
        uint32_t reorder_window = s_packets_reordered - s_last_report_packets_reordered;

        ESP_LOGI(TAG, "Istatistik: paket=%lu ort=%lu us (%.1f Hz) min=%lu us max=%lu us kayip=%lu reorder=%lu",
                 (unsigned long)s_interval_count,
                 (unsigned long)avg_us, hz,
                 (unsigned long)((s_interval_min_us == UINT32_MAX) ? 0 : s_interval_min_us),
                 (unsigned long)s_interval_max_us,
                 (unsigned long)loss_window,
                 (unsigned long)reorder_window);

        s_interval_min_us = UINT32_MAX;
        s_interval_max_us = 0;
        s_interval_sum_us = 0;
        s_interval_count = 0;
        s_last_report_ms = now_ms;
        s_last_report_packets_lost = state->packets_lost;
        s_last_report_packets_reordered = s_packets_reordered;
    }

    return false;
}

/**
 * @brief CONFIG_AP_MODE: bir döngü adimi (Bölüm 2).
 * @return true = NORMAL_MODE'a dönüş, false = devam.
 */
static bool config_ap_mode_step(s3_system_state_t *state)
{
    /* exit isteği kontrol */
    if (config_ap_exit_requested()) {
        return true;  /* NORMAL_MODE'a dön */
    }

    /* ADC akışı: son analog degerleri gonder */
    static uint32_t last_adc_send_ms = 0;
    uint32_t now_ms = (uint32_t)(esp_timer_get_time() / 1000);
    if ((now_ms - last_adc_send_ms) >= 10) {  /* 100 Hz ADC akışı */
        last_adc_send_ms = now_ms;
        uint16_t analog[12] = {0};
        for (int i = 0; i < 12; i++) {
            /* Son position'dan ADC'ye geri don (yaklasik) */
            analog[i] = (uint16_t)(state->keys[i].position * 4095.0f);
        }
        config_ap_send_adc(analog);
    }

    vTaskDelay(pdMS_TO_TICKS(10));
    return false;
}

void app_main(void)
{
    ESP_LOGI(TAG, "=== ESP32-S3 Dongle (tam) ===");
    ESP_LOGI(TAG, "IDF: %s  Target: %s", esp_get_idf_version(), CONFIG_IDF_TARGET);

    static s3_system_state_t state;
    if (init_subsystems(&state) != ESP_OK) {
        ESP_LOGE(TAG, "Init basarisiz");
        return;
    }

    ESP_LOGI(TAG, "Ana döngü basliyor (Bölüm 2 state machine)");

    while (1) {
        uint32_t now_ms = (uint32_t)(esp_timer_get_time() / 1000);
        bool boot_short_press = check_boot_button(now_ms);

        if (state.mode == S3_MODE_NORMAL) {
            /* NORMAL_MODE: boot button veya C6 config request → CONFIG_AP */
            if (boot_short_press || normal_mode_step(&state)) {
                ESP_LOGI(TAG, "CONFIG_AP_MODE'a geciliyor");
                config_ap_start(CONFIG_AP_SSID, CONFIG_AP_PASSWORD, CONFIG_AP_CHANNEL);
                state.mode = S3_MODE_CONFIG_AP;
            }
        } else {
            /* CONFIG_AP_MODE: boot button veya web exit → NORMAL */
            if (boot_short_press || config_ap_mode_step(&state)) {
                ESP_LOGI(TAG, "NORMAL_MODE'a donuluyor");
                config_ap_stop();
                uint8_t c6_mac[6] = {0};
                parse_mac(CONFIG_C6_PEER_MAC, c6_mac);
                espnow_rx_init(c6_mac, CONFIG_ESPNOW_CHANNEL);
                watchdog_feed();
                state.mode = S3_MODE_NORMAL;
            }
        }
    }
}

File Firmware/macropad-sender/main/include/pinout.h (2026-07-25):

// SPDX-License-Identifier: MIT-only
// Copyright (c) 2026 ESP32-C6 Macropad. All rights reserved.

/**
 * @file pinout.h
 * @brief ESP32-C6-MINI-1 donanım pin atamalarının tek kaynağı (single source of truth).
 *
 * Bu dosya projedeki TUM GPIO atamalarini icerir. Baska bir .c/.h dosyasinda
 * somut pin numarasi KULLANILMAMALIDIR; tum bilesenler pin numaralarini
 * init fonksiyonlari uzerinden main.c tarafindan alir.
 *
 * Kaynak: pcb_pinler.md (Hall Effect Macropad pin haritasi).
 *
 * Onemli notlar:
 *  - RXD0 (GPIO30) ve TXD0 (GPIO31) UART0 pinleri LED shift register'a
 *    ayrilmistir. Bu nedenle log cikisi USB-CDC uzerinden yapilir
 *    (bkz. sdkconfig.defaults: CONFIG_ESP_CONSOLE_USB_CDC=y).
 *  - IO8 ve IO9 strapping pinleridir; firmware'de kullanilmaz.
 *  - IO12/IO13 USB D+/D- pinleridir; USB peripheral tarafindan yonetilir,
 *    manuel GPIO yapilandirmasi gerektirmez.
 *  - VBUS ve /CHG sinyallerinin pin routing'i henuz netlesmedigi icin
 *    -1 (stub) olarak tanimlanmistir; charger_if bileseni bu durumu soyutlar.
 *  - SW2 (Layer Butonu) ve ENC_BTN direk GPIO DEGILDIR; U30 (SN74HC165)
 *    shift register'inin E/F pinlerinden okunur (bkz. shift_in_sn74hc165).
 *  - Diot-OR hatti (IO4 WAKEUP) yalnizca 12 dijital tusun OR'lanmis halidir.
 *    Encoder ve SR uzerinden okunan butonlar bu hatta bagli degildir.
 */
#pragma once

#ifdef __cplusplus
extern "C" {
#endif

/* =========================================================================
 * SPI bus (MCP3202 ADC icin donanimsal SPI)
 * Not: SCK (IO6) SN74HC165 ve 74HC595 shift register'lariyla ORTAKTIR.
 *       SR'lar bit-banging ile surulurken ayni SCK pini kullanilir.
 * ========================================================================= */
#define PIN_SPI_SCK          (6)    ///< U35 (ADC) + U29/U30 (dijital tus SR) + U14 (LED SR) ortak clock
#define PIN_SPI_MISO         (2)    ///< U35 ADC DOUT (analog okuma)
#define PIN_SPI_MOSI         (3)    ///< U35 ADC DIN
#define PIN_ADC_CS           (7)    ///< U35 ~CS (MCP3202)

/* =========================================================================
 * Dijital Tus Shift Register (SN74HC165 x2, bit-bang)
 * 24-bit zincirli okuma; ilk 12 bit TCS40DLR durumlaridir.
 * ========================================================================= */
#define PIN_SR_LATCH         (0)    ///< U29/U30 SH/~LD (latch / ornekleme)
#define PIN_SR_DATA          (1)    ///< U29 QH (seri veri cikisi), 24 bit shift-in

/* =========================================================================
 * LED Shift Register (74HC595, bit-bang)
 * Durum/layer LED'leri D8-D11 icin. SCK ortak (PIN_SPI_SCK).
 * ========================================================================= */
#define PIN_LED_SR_RCLK      (30)   ///< U14 RCLK (latch) — RXD0 pininin GPIO kullanimi
#define PIN_LED_SR_SER       (31)   ///< U14 SER (seri veri) — TXD0 pininin GPIO kullanimi

/* =========================================================================
 * Analog Coklayici (CD74HC4067)
 * S0-S3 ile 0-15 arasi kanal secilir. Kullanilan: ANA_KEY_0..11 (kanal 0-11).
 * Kanal 12-15: pil voltaj boleni / /CHG gibi ek sinyaller icin reserve.
 * ========================================================================= */
#define PIN_MUX_S0           (18)
#define PIN_MUX_S1           (19)
#define PIN_MUX_S2           (20)
#define PIN_MUX_S3           (15)
#define MUX_CHANNEL_ANALOG_KEY_COUNT  (12)  ///< ANA_KEY_0..11
#define MUX_CHANNEL_BATTERY           (12)  ///< Pil voltaj boleni (stub; donanim netlesince guncellenecek)
#define MUX_CHANNEL_CHG_STAT          (13)  ///< /CHG sinyali (stub; donanim netlesince guncellenecek)

/* =========================================================================
 * Guc Kontrolu
 * ========================================================================= */
#define PIN_TPS_EN           (14)   ///< U33 boost regulator enable (5V_LED hatti — LED'ler icin)
#define PIN_ANALOG_PWR_EN    (21)   ///< Q1 (P-FET) gate — analog Hall sensörleri + mux gucu (pil tasarrufu)

/* =========================================================================
 * Neopixel (SK6812MINI, 12 LED daisy-chain)
 * ========================================================================= */
#define PIN_NEOPIXEL_DATA    (5)    ///< U34 level shifter uzerinden NEO1-12
#define NEOPIXEL_LED_COUNT   (12)

/* =========================================================================
 * Encoder (donanimsal PCNT)
 * ========================================================================= */
#define PIN_ENC_A            (22)   ///< Filtrelenmis (R43/C9)
#define PIN_ENC_B            (23)   ///< Filtrelenmis (R42/C10)
/* ENC_BTN ve SW2 direk GPIO DEGILDIR; U30 SN74HC165 E/F pinlerinden okunur.
 * Bu sabitler yalnizca SR okuma sonrasi bit konumlarini belirtmek icin kullanilir
 * (bkz. shift_in_sn74hc165.h). */
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

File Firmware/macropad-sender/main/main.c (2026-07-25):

// SPDX-License-Identifier: MIT-only
// Copyright (c) 2026 ESP32-C6 Macropad. All rights reserved.

/**
 * @file main.c
 * @brief ESP32-C6 Macropad ana giris noktasi. Bölüm 2 ana döngü.
 *
 * Öncelik sirasi (Bölüm 2.1):
 *   1. Şarj denetimi (Bölüm 5)
 *   2. Kritik pil (Bölüm 4.4 deep sleep)
 *   3. Kombinasyon (Bölüm 6 - ATLANDI)
 *   4. Mod degisim (SW2 + encoder, Bölüm 2.1.4)
 *   5. Parlaklik degisim (Tuş12 + encoder, Bölüm 2.1.5)
 *   6. Sensör okuma + paket gönder (Bölüm 3)
 *   7. Pil ölçüm (10 sn'de bir, Bölüm 4.4)
 *   8. Güç modu sleep (Bölüm 4.1/4.2)
 */

#include <stdio.h>
#include <string.h>
#include "freertos/FreeRTOS.h"
#include "freertos/task.h"
#include "esp_log.h"
#include "esp_system.h"
#include "esp_check.h"
#include "esp_timer.h"

#include "pinout.h"
#include "system_state.h"

#include "nvs_store.h"
#include "spi_bus.h"
#include "mcp3202.h"
#include "mux_cd74hc4067.h"
#include "shift_in_sn74hc165.h"
#include "shift_out_74hc595.h"
#include "encoder.h"
#include "neopixel.h"
#include "power_ctrl.h"
#include "battery.h"
#include "charger_if.h"
#include "packet.h"
#include "espnow_link.h"
#include "wakeup_manager.h"

static const char *TAG = "macropad";

/** Shift register bit sayisi (algoritma 16, pcb 24 - Kconfig'e tasinacak). */
#define SHIFT_IN_BITS 16
#define SHIFT_OUT_BITS 8

/* SR bit mapping (VARSAYIM - donanim testinde dogrulanacak):
 *   sr_val bit0-11: 12 dijital tuş (bit0=Tus1..bit11=Tus12)
 *   sr_val bit2    : SW2 (U30 F) - OVERLAP! DÜZELTME GEREKLI
 * Asil mapping: SN74HC165 H=bit0..A=bit7. U30 E=bit3, F=bit2.
 * digital_buttons = sr_val & 0x0FFF (alt 12 bit)
 * SW2 = (sr_val >> 2) & 1, ENC_BTN = (sr_val >> 3) & 1
 * @note Bu mapping DONANIM TESTI ile dogrulanmali. */
#define SR_SW2_BIT       2
#define SR_ENC_BTN_BIT   3
#define SR_BUTTONS_MASK  0x0FFFu

/** MAC string parse: "AA:BB:CC:DD:EE:FF" -> uint8_t[6]. */
static void parse_mac(const char *str, uint8_t mac[6])
{
    if (sscanf(str, "%2hhx:%2hhx:%2hhx:%2hhx:%2hhx:%2hhx",
               &mac[0], &mac[1], &mac[2], &mac[3], &mac[4], &mac[5]) != 6) {
        ESP_LOGW(TAG, "MAC parse hatasi, default FF kullaniliyor");
        memset(mac, 0xFF, 6);
    }
}

/**
 * @brief Tum bilesenleri baslatir (Bölüm 1.1 + 1.2).
 */
static esp_err_t init_subsystems(system_state_t *state)
{
    memset(state, 0, sizeof(*state));

    /* 1. NVS + kalici ayarlar */
    ESP_RETURN_ON_ERROR(nvs_store_init(), TAG, "nvs_store_init");

    uint8_t mode_u8 = 0;
    nvs_store_get_u8("pw_mode", CONFIG_ACTIVE_POWER_MODE_DEFAULT, &mode_u8);
    state->config.active_power_mode =
        (mode_u8 <= POWER_MODE_AGGRESSIVE) ? (power_mode_t)mode_u8 : POWER_MODE_HYBRID;
    nvs_store_get_u8("brightness", CONFIG_BASE_BRIGHTNESS_DEFAULT,
                     &state->config.base_brightness);
    nvs_store_get_u8("layer", CONFIG_ACTIVE_LAYER_DEFAULT,
                     &state->config.active_layer);

    /* 2. SPI bus + cevresel */
    ESP_RETURN_ON_ERROR(spi_bus_init(PIN_SPI_SCK), TAG, "spi_bus");
    ESP_RETURN_ON_ERROR(mcp3202_init(PIN_ADC_CS, PIN_SPI_MISO, PIN_SPI_MOSI), TAG, "mcp3202");
    ESP_RETURN_ON_ERROR(mux_cd74hc4067_init(PIN_MUX_S0, PIN_MUX_S1, PIN_MUX_S2, PIN_MUX_S3), TAG, "mux");
    ESP_RETURN_ON_ERROR(shift_in_sn74hc165_init(PIN_SR_LATCH, PIN_SR_DATA, SHIFT_IN_BITS), TAG, "shift_in");
    ESP_RETURN_ON_ERROR(shift_out_74hc595_init(PIN_LED_SR_RCLK, PIN_LED_SR_SER, SHIFT_OUT_BITS), TAG, "shift_out");

    /* 3. Encoder */
    ESP_RETURN_ON_ERROR(encoder_init(PIN_ENC_A, PIN_ENC_B), TAG, "encoder");

    /* 4. Neopixel + power */
    ESP_RETURN_ON_ERROR(neopixel_init(PIN_NEOPIXEL_DATA, NEOPIXEL_LED_COUNT), TAG, "neopixel");
    ESP_RETURN_ON_ERROR(power_ctrl_init(PIN_ANALOG_PWR_EN, PIN_TPS_EN), TAG, "power_ctrl");

    /* 5. Battery + charger */
    battery_init();
    ESP_RETURN_ON_ERROR(charger_if_init(PIN_VBUS_SENSE, PIN_CHG_STAT), TAG, "charger_if");

    /* 6. ESP-NOW */
    uint8_t peer_mac[6] = {0};
    parse_mac(CONFIG_S3_PEER_MAC, peer_mac);
    ESP_RETURN_ON_ERROR(
        espnow_link_init(peer_mac, CONFIG_ESPNOW_CHANNEL, CONFIG_ESPNOW_FAILSAFE_THRESHOLD),
        TAG, "espnow_link");

    /* 7. Wakeup manager */
    ESP_RETURN_ON_ERROR(wakeup_manager_init(PIN_WAKEUP_DIOT_OR, true), TAG, "wakeup");

    /* Runtime state (Bölüm 1.1) */
    state->link.is_connected_to_s3 = true;
    state->link.consecutive_failed_packets = 0;
    state->link.search_mode = false;
    state->battery_dead = false;
    state->charging = false;
    state->charge_complete = false;
    state->inactivity_timer_ms = 0;
    state->packet_counter = 0;

    ESP_LOGI(TAG, "Tum bilesenler baslatildi. Mode=%d Bright=%u%%",
             state->config.active_power_mode, state->config.base_brightness);
    return ESP_OK;
}

/**
 * @brief Bölüm 5: Şarj modu denetimi.
 * @return true = şarj modunda (ana döngü continue), false = normal calisma.
 */
static bool step_charge_check(system_state_t *state)
{
    bool charging = charger_if_is_charging();
    if (!charging) {
        /* USB cekildi: şarj tamamlandi animasyonu varsa söndür */
        if (state->charge_complete) {
            neopixel_clear();
            power_ctrl_led_power(false);
            state->charge_complete = false;
        }
        return false;
    }

    /* İlk şarj algilama: flag sıfırla + başlangıç animasyonu */
    if (!state->charging) {
        state->charging = true;
        charger_if_clear_battery_flags(&state->battery_flags);
        charger_if_play_charge_start_animation();
    }

    /* Şarj tamamlandi kontrolü */
    if (charger_if_is_charge_complete() && !state->charge_complete) {
        state->charge_complete = true;
        charger_if_play_charge_complete_animation();
    }
    return true;  /* şarj modunda kal */
}

/**
 * @brief Bölüm 4.4: Kritik pil kilidi. battery_dead ise deep sleep.
 * @return true = deep sleep'e girildi (döngü çıkar), false = devam.
 */
static bool step_critical_battery(system_state_t *state)
{
    if (!state->battery_dead) {
        return false;
    }
    ESP_LOGW(TAG, "Kritik kilitle: deep sleep (Bölüm 4.4)");
    /* ESP-NOW + analog guc kapat */
    power_ctrl_analog_power(false);
    power_ctrl_led_power(false);
    wakeup_manager_deep_sleep();  /* donmez */
    return true;
}
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

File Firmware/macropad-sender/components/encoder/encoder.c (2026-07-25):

// SPDX-License-Identifier: MIT-only
// Copyright (c) 2026 ESP32-C6 Macropad. All rights reserved.

/**
 * @file encoder.c
 * @brief Rotary encoder PCNT v2 quadrature decode implementasyonu.
 */

#include "encoder.h"

#include "esp_log.h"
#include "driver/pulse_cnt.h"

static const char *TAG = "encoder";

/** PCNT unit handle (file-local static, AI_GUIDELINES.md kural 16). */
static pcnt_unit_handle_t s_unit = NULL;

/** PCNT channel handle. */
static pcnt_channel_handle_t s_chan = NULL;

static bool s_initialized = false;

esp_err_t encoder_init(int phase_a_gpio, int phase_b_gpio)
{
    if (s_initialized) {
        return ESP_OK;
    }
    if (phase_a_gpio < 0 || phase_b_gpio < 0) {
        ESP_LOGE(TAG, "Gecersiz pin: A=%d B=%d", phase_a_gpio, phase_b_gpio);
        return ESP_ERR_INVALID_ARG;
    }

    /* PCNT unit: genis limit (delta birikebilsin) */
    pcnt_unit_config_t unit_cfg = {
        .low_limit  = -32768,
        .high_limit = 32767,
    };
    esp_err_t ret = pcnt_new_unit(&unit_cfg, &s_unit);
    if (ret != ESP_OK) {
        ESP_LOGE(TAG, "pcnt_new_unit hatasi: %s", esp_err_to_name(ret));
        return ret;
    }

    /* Glitch filter: PCB'de RC filtre (R43/C9, R42/C10) var, ek yazilim filtresi
       kisa (1us) - cift sayimi onler. */
    pcnt_glitch_filter_config_t glitch_cfg = {
        .max_glitch_ns = 1000,
    };
    pcnt_unit_set_glitch_filter(s_unit, &glitch_cfg);

    /* PCNT channel: A=edge, B=level */
    pcnt_chan_config_t chan_cfg = {
        .edge_gpio_num  = phase_a_gpio,
        .level_gpio_num = phase_b_gpio,
    };
    ret = pcnt_new_channel(s_unit, &chan_cfg, &s_chan);
    if (ret != ESP_OK) {
        ESP_LOGE(TAG, "pcnt_new_channel hatasi: %s", esp_err_to_name(ret));
        pcnt_del_unit(s_unit);
        s_unit = NULL;
        return ret;
    }

    /* Quadrature 4x decode:
     *   edge_action: pos=INCREASE (A rising), neg=DECREASE (A falling)
     *   level_action: high=INVERSE (B high -> edge action'ları ters çevir),
     *                low=KEEP (B low -> edge action'ları koru)
     * Sonuc: tam 4x quadrature, CW=artı, CCW=eksi */
    pcnt_channel_set_edge_action(s_chan,
                                 PCNT_CHANNEL_EDGE_ACTION_INCREASE,  /* pos edge */
                                 PCNT_CHANNEL_EDGE_ACTION_DECREASE); /* neg edge */
    pcnt_channel_set_level_action(s_chan,
                                  PCNT_CHANNEL_LEVEL_ACTION_KEEP,    /* B high */
                                  PCNT_CHANNEL_LEVEL_ACTION_INVERSE);/* B low  */

    /* Enable + start */
    ESP_ERROR_CHECK(pcnt_unit_enable(s_unit));
    ESP_ERROR_CHECK(pcnt_unit_start(s_unit));
    ESP_ERROR_CHECK(pcnt_unit_clear_count(s_unit));

    s_initialized = true;
    ESP_LOGI(TAG, "Encoder baslatildi: A=GPIO%d B=GPIO%d (quadrature 4x)",
             phase_a_gpio, phase_b_gpio);
    return ESP_OK;
}

int16_t encoder_get_delta(void)
{
    if (!s_initialized || s_unit == NULL) {
        return 0;
    }

    int count = 0;
    esp_err_t ret = pcnt_unit_get_count(s_unit, &count);
    if (ret != ESP_OK) {
        ESP_LOGE(TAG, "pcnt_unit_get_count hatasi: %s", esp_err_to_name(ret));
        return 0;
    }

    /* Sayaci sifirla (delta bir sonraki cagri icin sifirdan baslar) */
    pcnt_unit_clear_count(s_unit);

    /* int -> int16_t (limitler -32768..32767, tek okumada tasmaz) */
    if (count > 32767) {
        count = 32767;
    } else if (count < -32768) {
        count = -32768;
    }
    return (int16_t)count;
}

void encoder_clear(void)
{
    if (s_initialized && s_unit != NULL) {
        pcnt_unit_clear_count(s_unit);
    }
}

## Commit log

2026-07-25 feat: initial commit - custom wireless keyboard firmware
2026-07-25 added Kicad files
    [macropad.kicad_pcb, macropad.kicad_sch]
2026-07-25 added gerber files
    [macropad-B_Cu.gbr, macropad-B_Mask.gbr, macropad-B_Paste.gbr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]
2026-11-05 Update prototype, documentation and component release baselines
2026-11-05 Add experimental three-slot BLE switching
2026-11-05 Show selected BLE slot and guard stale events
2026-11-05 Reject known BLE hosts from other selected slots
2026-11-05 Improve BLE reconnection and selected host filtering
2026-11-05 Record BLE tests and sensor scope
2026-11-05 Hide sensor panels in BLE mode
